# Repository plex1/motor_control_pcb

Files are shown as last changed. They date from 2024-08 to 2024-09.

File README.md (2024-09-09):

# Motor Control PCB 

Mainly an carrier for the follwing modules:
- 1x [A-Star 328PB Micro](https://www.pololu.com/category/239/a-star-328pb-micro) (compatible with Arduino)
  - 3.3 V, 12 MHz version (yellow power LED)
- 2x [DRV8834 Low-Voltage Stepper Motor Driver Carrier](https://www.pololu.com/product/2134)

## Libraries

Uses the following libraries:
- KiCad Symbol Library: [ioda_symbols](https://github.com/plex1/ioda_symbols)
- KiCad Footprint Library: [ioda_footprints](https://github.com/plex1/ioda_footprints)

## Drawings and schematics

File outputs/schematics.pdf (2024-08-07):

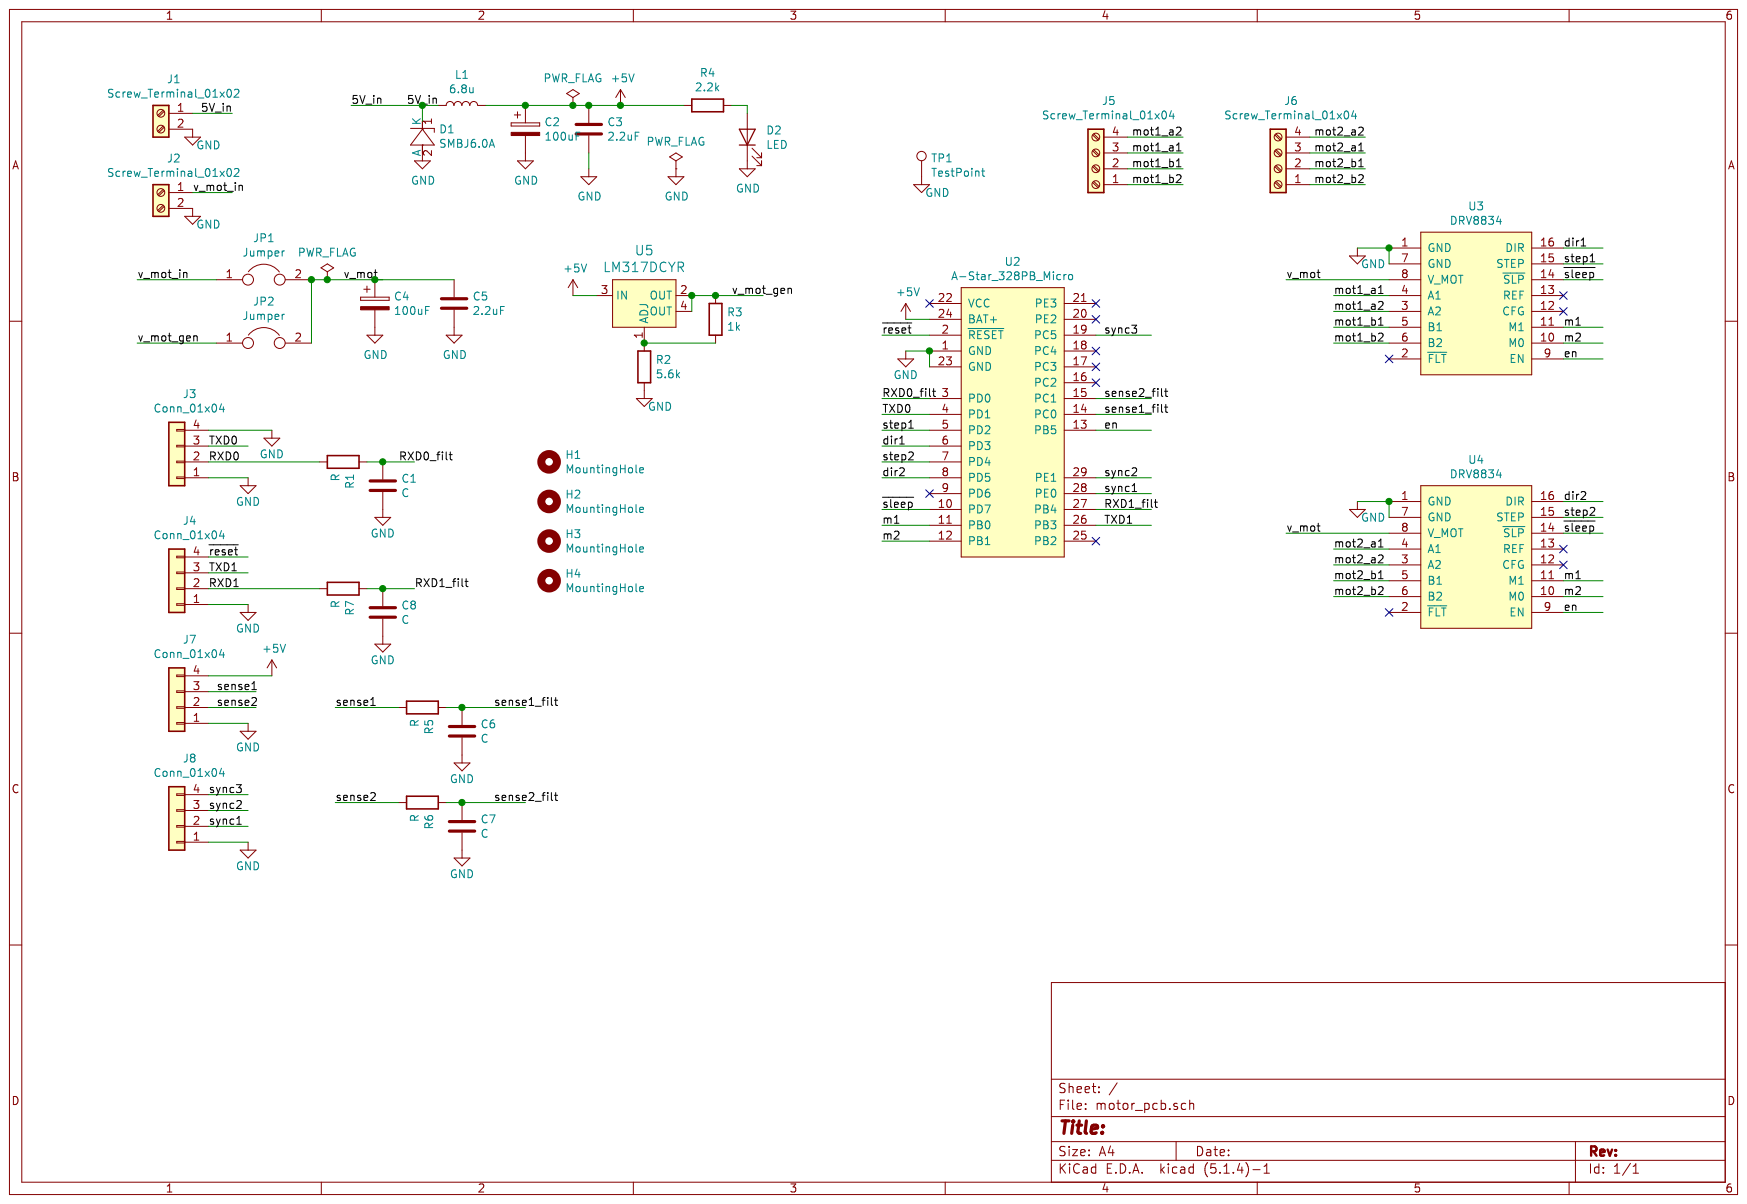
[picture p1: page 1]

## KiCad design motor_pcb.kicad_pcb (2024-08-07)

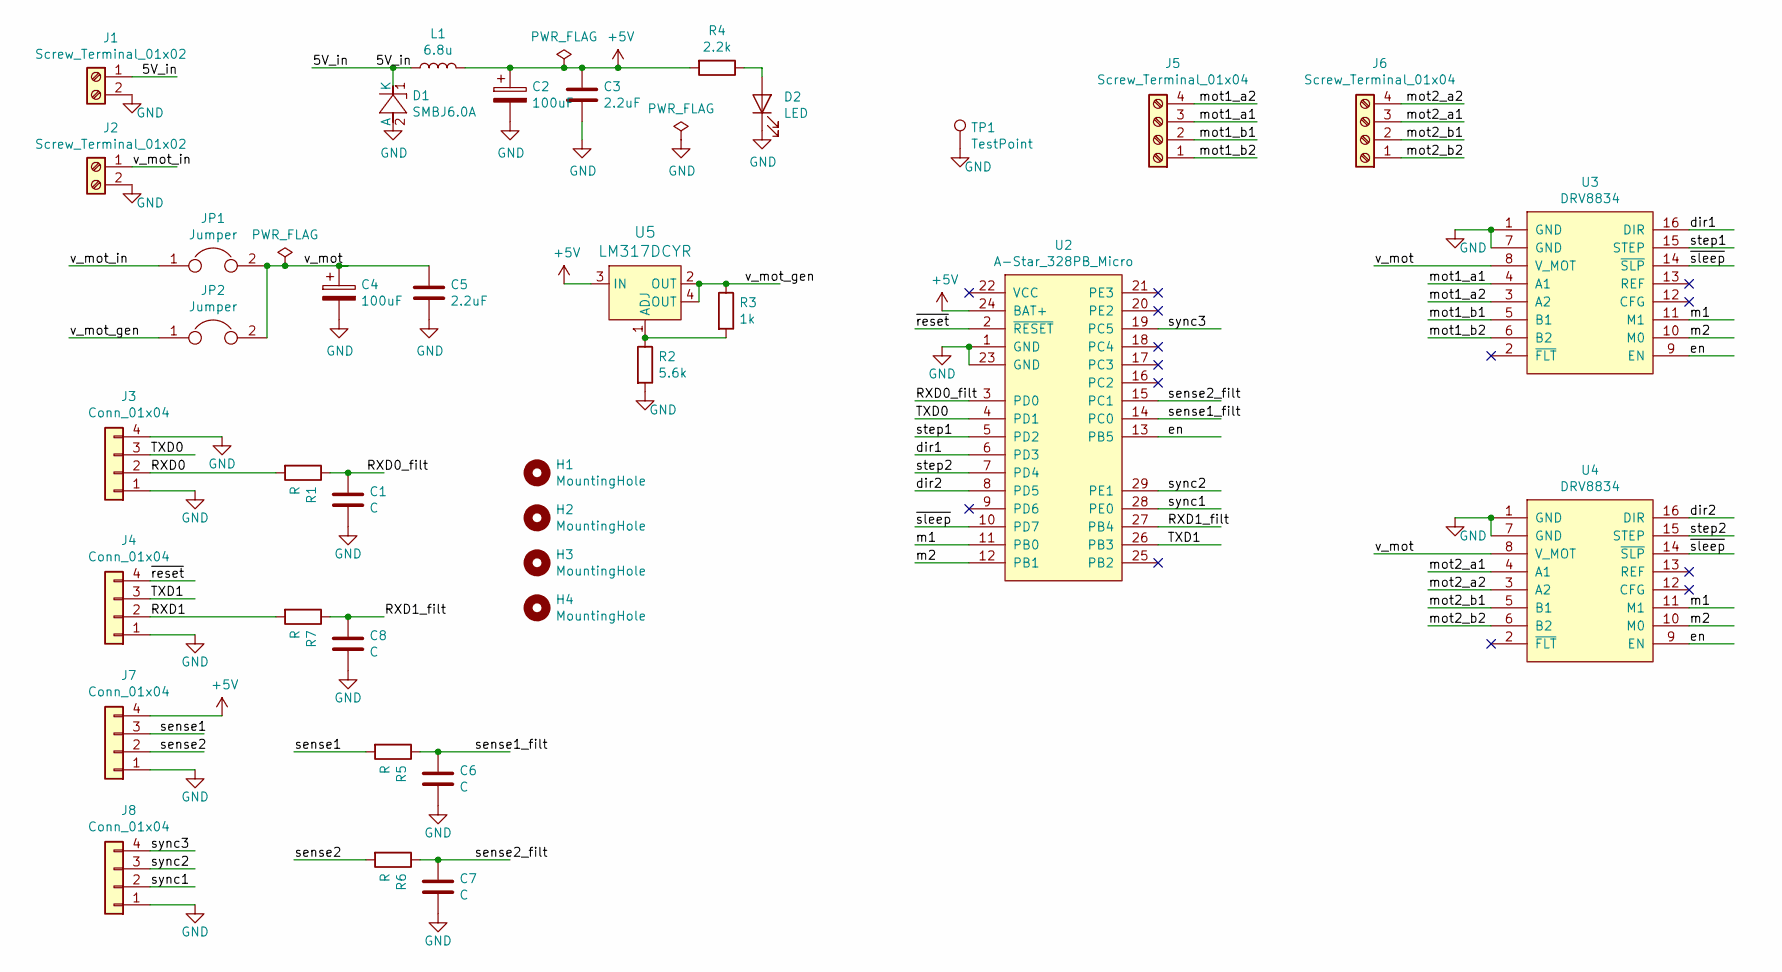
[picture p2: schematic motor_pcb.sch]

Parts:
C1, C6, C7, C8: C; C_0603_1608Metric
C2, C4: 100uF; CAPAE660X800N; Digi-Key_PN PCE5024CT-ND
C3, C5: 2.2uF; C_0603_1608Metric; Digi-Key_PN 490-12740-1-ND
D1: SMBJ6.0A; DO214AA_1(K)-2(A); Digi-Key_PN SMBJ6.0ABCT-ND
D2: LED; LED_0805; Digi-Key_PN 160-1423-1-ND
H1, H2, H3, H4: MountingHole; MountingHole_3.2mm_M3
J1, J2: Screw_Terminal_01x02; ScrewTerminal_1x02_P2.54mm_Vertical; Digi-Key_PN A98333-ND
J3, J4, J7, J8: Conn_01x04; Molex_PicoBlade_53261-0471_1x04-1MP_P1.25mm_Horizontal
J5, J6: Screw_Terminal_01x04; PinHeader_1x04_P2.54mm_Vertical
JP1, JP2: Jumper; R_0805_2012Metric
L1: 6.8u; INDP7373X46N; Digi-Key_PN 811-1180-1-ND
R1, R5, R6, R7: R; R_0603_1608Metric
R2: 5.6k; R_0603_1608Metric
R3: 1k; R_0603_1608Metric
R4: 2.2k; R_0603_1608Metric; Digi-Key_PN RMCF0603FT2K20CT-ND
TP1: TestPoint; PinHeader_1x01_P1.27mm_Vertical
U2: A-Star_328PB_Micro; DIP-24_600_ELL_15.24mm-spacing
U3, U4: DRV8834; DIP-16_500_ELL_12.7mm-spacing
U5: LM317DCYR; SOT-223-4; MPN LM317DCYR; Digi-Key_PN 296-12602-1-ND

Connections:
+5V: C2.1, C3.1, J7.4, L1.2, R4.2, U2.24 (BAT+), U5.3 (IN)
/5V_in: D1.1 (K), J1.1, L1.1
/RXD0: J3.2, R1.2
/RXD0_filt: C1.1, R1.1, U2.3 (PD0)
/RXD1: J4.2, R7.2
/RXD1_filt: C8.1, R7.1, U2.27 (PB4)
/TXD0: J3.3, U2.4 (PD1)
/TXD1: J4.3, U2.26 (PB3)
/dir1: U2.6 (PD3), U3.16 (DIR)
/dir2: U2.8 (PD5), U4.16 (DIR)
/en: U2.13 (PB5), U3.9 (EN), U4.9 (EN)
/m1: U2.11 (PB0), U3.11 (M1), U4.11 (M1)
/m2: U2.12 (PB1), U3.10 (M0), U4.10 (M0)
/mot1_a1: J5.3, U3.4 (A1)
/mot1_a2: J5.4, U3.3 (A2)
/mot1_b1: J5.2, U3.5 (B1)
/mot1_b2: J5.1, U3.6 (B2)
/mot2_a1: J6.3, U4.4 (A1)
/mot2_a2: J6.4, U4.3 (A2)
/mot2_b1: J6.2, U4.5 (B1)
/mot2_b2: J6.1, U4.6 (B2)
/sense1: J7.3, R5.2
/sense1_filt: C6.1, R5.1, U2.14 (PC0)
/sense2: J7.2, R6.2
/sense2_filt: C7.1, R6.1, U2.15 (PC1)
/step1: U2.5 (PD2), U3.15 (STEP)
/step2: U2.7 (PD4), U4.15 (STEP)
/sync1: J8.2, U2.28 (PE0)
/sync2: J8.3, U2.29 (PE1)
/sync3: J8.4, U2.19 (PC5)
/v_mot: C4.1, C5.1, JP1.2, JP2.2, U3.8 (V_MOT), U4.8 (V_MOT)
/v_mot_gen: JP2.1, R3.1, U5.2 (OUT), U5.4 (OUT)
/v_mot_in: J2.1, JP1.1
/~reset: J4.4, U2.2 (~RESET)
/~sleep: U2.10 (PD7), U3.14 (~SLP), U4.14 (~SLP)
GND: C1.2, C2.2, C3.2, C4.2, C5.2, C6.2, C7.2, C8.2, D1.2 (A), D2.1 (K), J1.2, J2.2, J3.1, J3.4, J4.1, J7.1, J8.1, R2.2, TP1.1, U2.1 (GND), U2.23 (GND), U3.1 (GND), U3.7 (GND), U4.1 (GND), U4.7 (GND)
unnamed: D2.2 (A), R4.1
unnamed: R2.1, R3.2, U5.1 (ADJ)

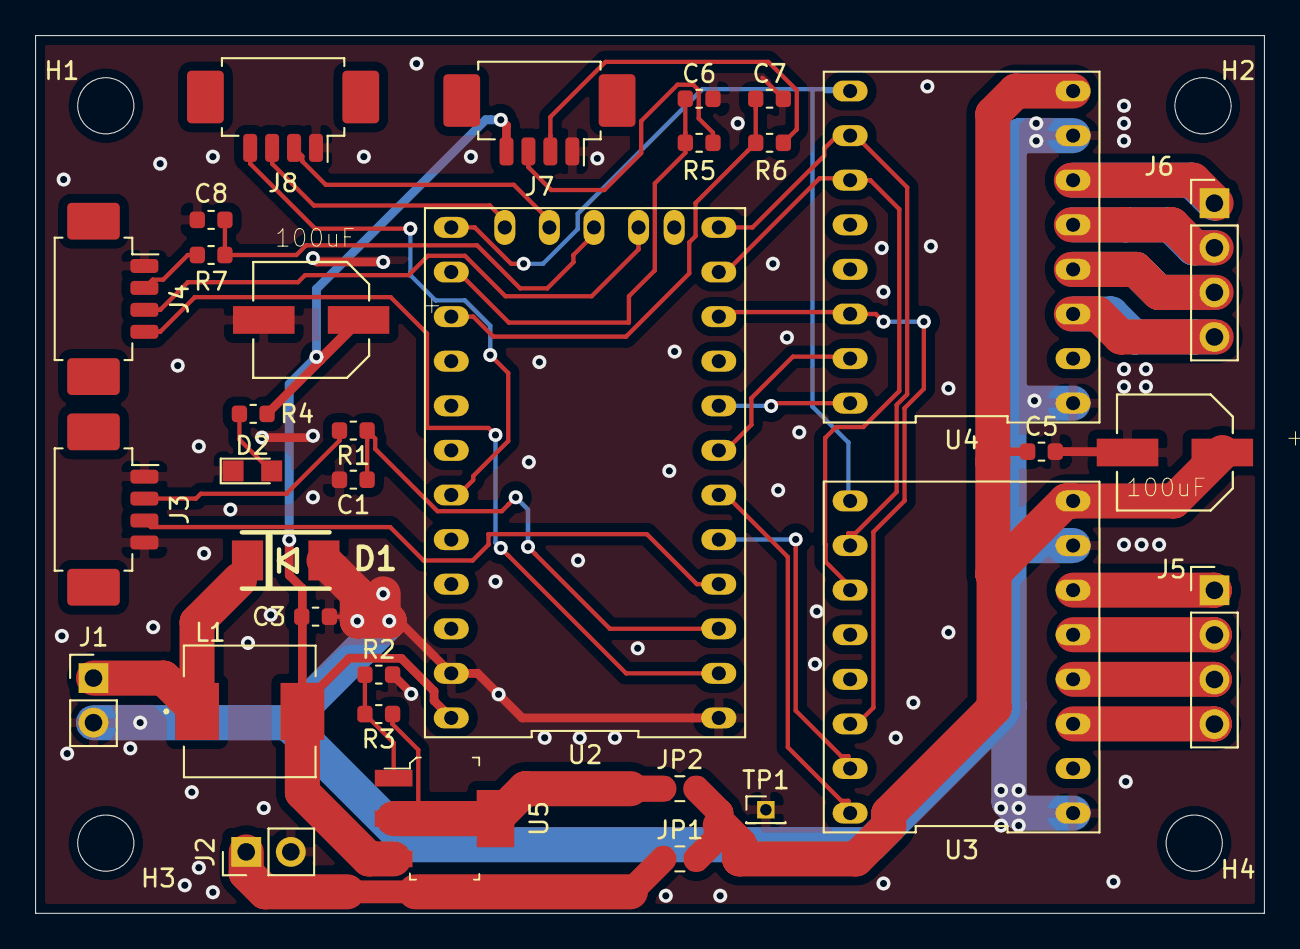
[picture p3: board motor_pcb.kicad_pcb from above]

Board: 2 copper layers, 70.0 x 50.0 mm, 37 parts (0 on the bottom side), 38 nets.

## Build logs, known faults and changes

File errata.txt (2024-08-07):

put silkscreen 5V+ 5V-
footprint for astart not 100% correct with positions of the pins in the top row
tracks for phases to J5 are missing on bottom layer
lm317 dorpout of 3V recommended. Idea was to use 4.3V for motor -> dropout only 0.7
also the voltage divider on lm317 has wrong values (vref = 1.25V, vref between output and adjust)

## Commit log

2019-11-19 Initial version
    [motor_pcb.kicad_pcb, motor_pcb.sch]
2019-11-19 added 5V to sensor connector
    [motor_pcb.kicad_pcb, motor_pcb.sch]
2024-08-07 updated with previously uncommitted changes. Added schematics
    [motor_pcb.kicad_pcb, motor_pcb.sch]
